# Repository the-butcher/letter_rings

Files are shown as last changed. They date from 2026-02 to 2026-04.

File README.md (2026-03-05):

# letter-rings

This is a fun project primarily for learning things. Following a specific theme for a partyI had been invited to an image of letters on each finger came to my mind, think of "LOVE" across the fingers of one hand and "HATE" on the other to have you own picture.

Since - for reasons - I did not want this as a permanent solution, something else had to be found.

I came across [8x8 LED Matrix elements](https://www.adafruit.com/product/870), small enough to be fitted to single fingers and added 3D printed rings. Cables would lead from the LED Matrix elements to a hidden [microcontroller](https://learn.adafruit.com/esp32-s3-reverse-tft-feather/overview) on my forearms. I wanted to enable the device to interact with the music being played, so I added a [microphone](https://www.adafruit.com/product/1063) for frequency analysis as well as an [orientation sensor](https://www.adafruit.com/product/4646?srsltid=AfmBOoqnGDiWn61naHonwXmNlG8PC3zfjmaNAw2MefeWkbG_hBlhx19s) so the matrices could adapt to arm position.

To avoid cable mess I ordered a simple PCB and 3D printed more parts to keep everything together. USB cables will lead to a powerbank capable to run the entire setup for many hours.

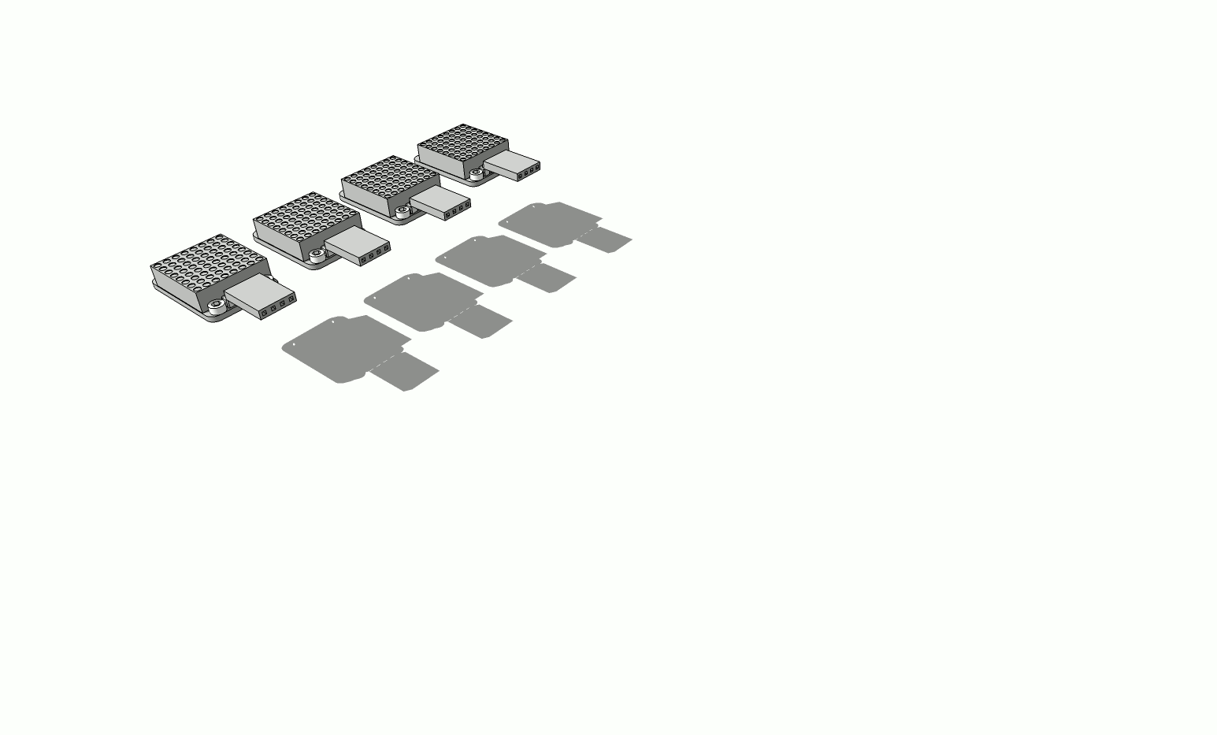
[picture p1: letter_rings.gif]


Would be nice to sync left and right? To add Bluetooth and a central device to take control I wrote an Android app, my first such app and maybe the most challenging part of this project. This app is in charge of synchronizing modes across devices.

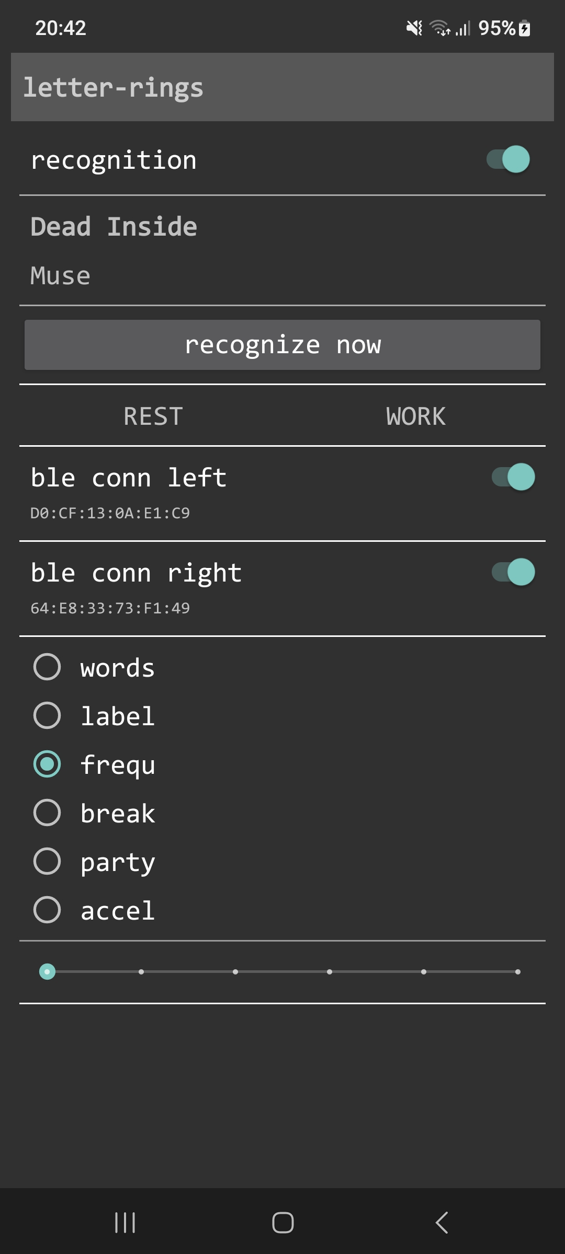
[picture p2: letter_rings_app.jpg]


There a multiple modes of operation ...

- WORDS

This mode refers to the original theme, "letters" and shows opposing pairs of words on the led matrices in radid succesion.



- LABEL

The app integrates [shazamkit](https://developer.apple.com/shazamkit/android/) for music recognition. The Android app records 10 second samples, and asks the Shazam Api for title and artist. When recognizable, tile and artist are shown as moving labels on the led matrices.

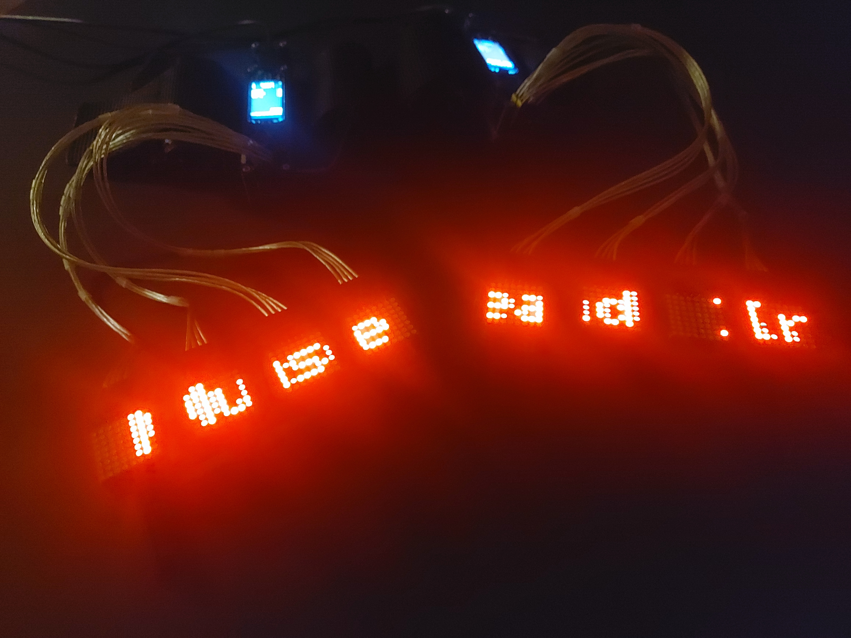
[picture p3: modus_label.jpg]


- FREQU

In this mode the devices frequency analysis is performed every 50 milliseconds (20 times per second), and the frequencies are displayed in disco style bars.

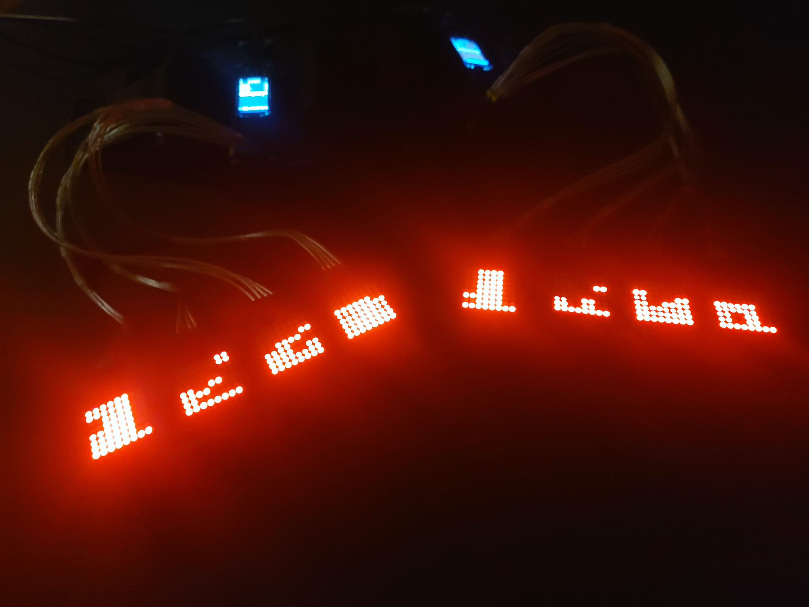
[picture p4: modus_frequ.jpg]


- BREAK

This is a "silent" mode, i.e. for when a conversation happens. A single dot travels through the led matrices.

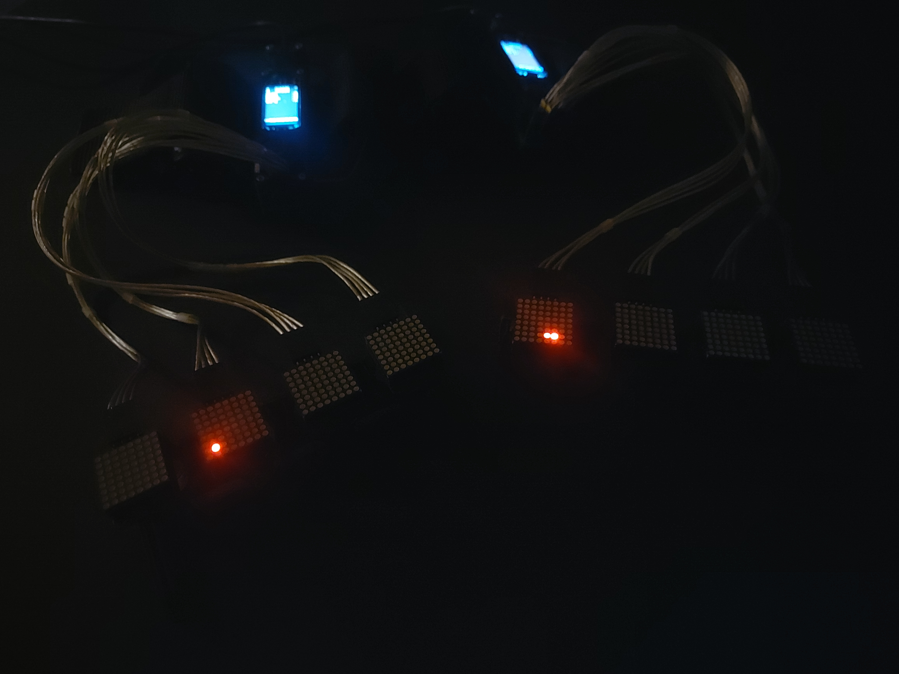
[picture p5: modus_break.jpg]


- ACCEL

Unfortunately no picture ... the orientation sensor records movements and upon detection of comment movement, i.e. both hands are held together, a PACMAN animation will run, consuming anything previously drawn on the matrices ;)

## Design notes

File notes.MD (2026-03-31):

✔️ reply to host

- android app
  ~~ try to identify code that can fail and handle errors accordingly, read more BLE tutorials
  ~~ possible/important to regularly check for BLE device having become available?
  ✔ lockability in app to prevent accidental touch events
  ✔ editability for labels in app 
  ❌ when the device disconnects before the gatt-services are in place there is no event or other notification
  ❌ attempting to connect from this state returns the app to a stable state (gatt connect fails and the UI shows the button again after that)
  ✔ integrate ChatGPT word list
  ✔ adapt the app so changes apply to all connected devices, this will simplify the UI and reduce room for error
  ✔ address does not hide when connection is lost
  ✔ generally no further bluetooth scans are done once a device connection is lost
  ✔ brightness slider
  ✔ have the catalog in a central place and reuse
  ✔️ learn how to parse the matchResult, including no-match cases
  ✔️ have continous parsing at specific intervals (i.e. 1 minute)
  ✔️ gatt connection to 2(!) devices, if that does not work maybe one device being server, one being client could be an alternative
  ✔️ find out about message size and how to split texts if needed
  ✔ handle GATT disconnect (update UI), roughly in place, but needs revisit,
  ✔ a switch disconnect in the app does not disconnect the device!

- esp
  ✔ trigger for kitt animation
  ✔ device does not return from PRI to Any :: did switch to WORDS due to false positive W pattern recognition
  ✔ actually render kitt animation depending on DTERM setting
  ✔ return all matrices to their original brightness when done with drawing the kitt animation
     -- does not work when switching modus while still in GAMKN animation, but can be recovered by manually setting brightness
  ~~ test with full setup, on arms and powerbank, wear for a while to discover problems, uncomfortable spots, short cables, ...
  ~~ check any thinkable maximum in terms of device orientation and be sure there is no problem throughout orientations
  ~~ test with high volume and noise as good as possible, experiment with gain settings on the microphone
     - https://leobot.net/tutorial/1067?srsltid=AfmBOopGwK3bNLB8GH9lWKwbYeUN1UAsiPBQsh7GJRLy7i_L0Uc4ghWd
  ✔ when entering words mode through gesture it can take a few seconds for the first words to appear
     -- also when changing UP/DOWN orientation it may take a bit
  ❌ maybe better display in accel mode, where the coefficient draws a bar with a threshold marker rather than just a number
  ✔ belts are a bit short when leading over the batteries :: TODO :: good enough?
  ✔ maybe it would work to record some accel patterns (i.e. bumping hands n-times, circling a hand), then calculating coefficients like in accel mode against those pattersn.
    ✔ determine duration a coefficient calculation consumes to get a feeling how often this can be done within loop limits
	✔ what would happen in case this works? - mode switch, "recognize now", ...
	✔ how would recording patterns work?
	✔ would recorded patterns have to be longer than the currently used accel pattern for pairing?
  ✔ condition when in accel mode where device becomes sluggish :: was due to extraDelay having large values after mode change
  ✔ introduce extra-delay
  ❌ introduce mutex around accelB (?) :: maybe not needed the way it is implemented, copying values into accelB
  ✔ do regression testing for all modes, especially acceleration related
  ✔ dont write to display after a certain time (1 minute, 5 mintues, ...) in an attempt to reduce noise and to save resources overall
    ✔ backlight could be off/low (even though the constant current likely does not introduce too much signal noise)
    ✔ wake the display upon config change through BLE
	✔ wake the display upon any button press
  ✔ reprint the pla_top part with a better mic hole center
    ✔ could also have cable fixture all around the dupont plugs
  ✔ reprint the usb cable fixture a tad higher and an opening that allows the cable diameter to be inserted, but not the larger diameter between plug and cable
  ✔ should brightness be adjustable beyond 5 :: 10 maybe?
  ✔ not sure if cubic curve still displays :: TODO :: check
  ❌ first call to party mode does not put the device into initial label mode, later calls work as expected
  ✔ make correlation threshold (0.80 currently) configurable to prevent weird behaviour when actually at the party and try to find possible default configuration
    ✔ new characteristic (like light)
	✔ slider in app
	✔ config in device
  ✔ test and measure the usb-c cables
    ✔ draw sensor protection and cable hold
    ✔ print and mount
  ✔ documentation
    ✔ github readme
    ✔ pictures, video for github and twitter
  ✔ print new ring holders
    ✔ ring holders could be more modular
    ✔ a single ring holder may offer better hold and protection for a single ring
      ✔ right hand is 23-24-23-20
      ✔ left hand is 24-24-22-20
  ✔ map raw bands to screen/matrix space
  ✔ build some sort of average from the most recent band values
  ✔ display delta from current measurement to average (aka less or more volume than previously)
  ❌ darken the green orientation sensor led with black edding
  ✔ modus accel is considerably slower when actually paired :: maybe the sens increase to 250ms :: solved with splitting the secondary tasks
  ✔ check how long a display write would normally consume, then maybe implement redraw regions to save some of that time
    ✔ was 14ms, now down to 5ms
  ✔ there should to be a "conversation" modus, where the leds are off or only a "standby" led is on
    ❌ any gesture to enable/disable this mode?
  ❌ sending or receiving through esp-now appears to disturb frequencies, try to move send calls to primary loop, receive would be more difficult :: does not work
  ❌ there is occasional lag when drawing matrices, where it seems the bitmap pos has proceeded multiple steps (~3) before an actual redraw
  ✔ mabe use the free 23mm for the right ring-finer (22 is a bit tight there)
  ✔ need another 24mm ring for left index finger (23 wont fit)
  ✔ it seems like high frequencies are over-represented in the spectrum
  ✔ check if order 3 regression on frequencies is OK :: seems to work better than order 2
  ✔ separate word sets for left and right
  ✔ have a mode (name?) where after a new label and some timeout it goes back to frequ
    ❌ could be standard, labels do not make much sense without recognition, therefore a new label could just put the decive in temp label mode
  ❌ any mode where altering brightness would add value?
  ✔ have proper matrix UP/DOWN flip in all modes
  ✔ unify method names Matrices vs. Matrix
  ✔ clearXXX function, execute properly after modus switch
  ✔ dim TFT a while after the last button press https://forums.adafruit.com/viewtopic.php?t=174096
  ✔ be able to switch modes
    ✔ through display
    ❌ through gesture (?)
    ✔ through bluetooth / mobile
  ❌ any other attractive modes?
    ❌ a mode "shaking" random chars by acceleration / position
    ❌ a mode that would write the word "beer" when lifting a bottle, would have to be a specific orientation change in a specific amount of time
    ❌ "collab" mode where people can "inject" labels
      ❌ would there be a non-backend solution?
      ❌ enter labels on a public website
      ❌ app fetches label and
      ❌ could this be a simple php solution working with a text or json file for storage?
    ❌ "kitt mode"
    ❌ a single dot travelling left to right and back
  ✔ any way to determine when left and right are held in alignment?
  ✔ setup task to read orientation in short intervals and keep track of the last n (some power of 2, maybe 32) acceleration vectors
  ✔ create esp-now connection between left and right
  ✔ send acceleration vectors to other device in regular intervals
  ✔ align vectors time-wise (how?)
  ✔ calculate pearson correlation coefficient between incoming acceleration data and own acceleration data
  ✔ see if this produces usable similarity results
  ✔ if both devices agree to have similar acceleration values unlock some (yet to be defines) two device mode
  ✔ should both devices always have the same mode?
  ✔ first device detecting similarity takes the lead
  ✔ other device will not need to check for similarity while paired
  ✔ leading device sends drawing codes, ie. kitt bar signal
  ✔ non-leading device needs to know when similarity was lost
  ❌ could be a kitt style animation (which device will be in charge of position?)
  ✔ could be a pacman style animation (which device will be in charge of position?)
  ✔ full width of matrices needs to be accounted for when paired :: with proper rotation
  ✔ the PRI device will also have to be in charge of maintaining a unique up/down orientation
  ❌ voice recognition for 4 letter words ;)
  ✔ ignore invalid titles for the runLabel
  ✔ maybe have a "song" mode that will show artist and title for a given time, then go back to frequencies
  ✔ any way to synchronize left and right in word mode?
  ✔ let the android app have the central role in words mode (only if connected)
  ✔ let the android app send pairs of words in regular intervals
  ✔ change words mode so that there always is a target word in words mode and a prepicked set of transition words
  ✔ when not connnected the devices can pick target words themselves, when connected the devices will wait for target words coming in over bluetooth
  ✔ define pairs of opposing words
  ✔ initial values of radio buttons after connect
  ✔ create a left UI version (?)
  ✔ screen could be oriented "upwards" to have an orientation common to left and right
  ✔ take care of readability (no font size = 1)
  ✔ byte to string parsing in the ESP32
  ✔️ microphone POC in the ESP32, preferrably amplifier style, but could also be led matrix brightness
  ✔ validate possibility of multiple led matrices on one i2c line
  ❌ could there be a generic blend function for labels?
  ❌ how would different lengths of labels be handled?
  ❌ original label longer than new label
  ❌ example:
  ❌ this is a very very very long label
  ❌ short label
  ❌ original label shorter than new label
  ✔ create some blend magic from one character to another
  ✔ could maybe work with offscreen canvas
  ✔ look at canvas.getBuffer()
  ✔ maybe a few random sequences including the number 0-63 and gradually changing from src to target values would do the trick
  ✔ check if there is a shuffle method for arrays in arduino
  ❌ rotate display upon hand position using blend effect
  ❌ current buffers of A and D (and B and C) would have to be swapped and rotated
  ✔ Lackstift gelb für Kabelmarkierungen @ müller
  ✔ punkt bei SCL auf der LED Matrix
  ❌ kurzes stück gelber schraumpfschlauch am SCL kabel, beidseitig
  ✔ und / oder dupont stecker auf der SCL seite gelb markiert  

✔ pcb
✔ order pcb after multi-matrix i2c validation

LOVE ICON GAIN HYPE UNDO COOL HOPE KISS MOON FEEL HELP DEAL FACT GAME KIND MIND DARE EARN WELL GROW JUMP KEEP BOLD CALM DEEP EASY GOOD FULL GLAD HIGH NEAR PULL PLUS SAVE FAST LIKE FREE
HERO BEST BODY DEAR FACE FLOW LEAD USER YEAH PEAK FUND LIST NEWS PAIR LIST NOTE SELF BASS FINE BLUE HALF LIVE LONG HOUR LOOK MARK MOVE LIFT GOAL BAND SOFT CARE PURE FUND STAY MORE WARM
LAMB TEAM VIEW REAL HAVE LINK RISE RELY WISH WAIT TALK REST MANY RICH KNOW JOIN RIDE TIDY HUGE HEAL NICE OKAY FAIR NEAT TRUE LIFE

HATE FAIL GANG JUNK FAKE BAIT CAGE SCAR SLOW WOLF PAIN TINY LUSH FIRE FUCK LESS LOSS BURN DENY FALL FEAR HURT KILL NONE EVIL DULL FOUL GRIM DAMN GORE GOSH HELL LATE DUST DARK DUTY RISK
WARN SLIP UGLY WILD VAIN POOR MEAN RUDE SORE VOID ANTI DIRE COPE COST PUSH MYTH URGE RAIN REDO NEED SEEM LONE VAST PALE SICK RARE BEEF FOOL DEAF DRUG ITCH PITY LACK WANT SEEK TRIP DOWN
GREY RULE WORK TASK STOP LOUD MUST GIVE LOSE TORN ONLY SOLO TRAP FLOP QUIT SUNK HOWL ENVY CYST COLD DROP BASE FLEE OVER HARD PASS

https://www.powerthesaurus.org/huge/antonyms

STEW SOUP
LOVE HATE
REAL FAKE
WARM COLD
MANY NONE
FAST SLOW
KIND GRIM
GOOD EVIL
TAKE GIVE
WELL SICK
HOPE FEAR
FACT MYTH
RISE FALL
MORE LESS
MOVE STOP
REST WORK
HEAL HURT
LIFT DROP
SOFT HARD
CALM LOUD
RICH POOR
PURE FOUL
NICE MEAN
PEAK BASE
PULL PUSH
LAMB WOLF
TALL TINY
FULL HALF
STAY FLEE
UNDO REDO
LIVE PASS
FIND LOSE
GAIN LOSS
OPEN SHUT
EAST WEST
HIGH DEEP
DAWN DUSK
ROCK ROLL
GOLD IRON
SAFE RISK
GROW FADE
CODE DATA
ROPE KNOT
BEER WINE
SKIN BONE
FACE MASK
MIND BODY
HIDE SEEK
LUCK FATE
WEAK FIRM

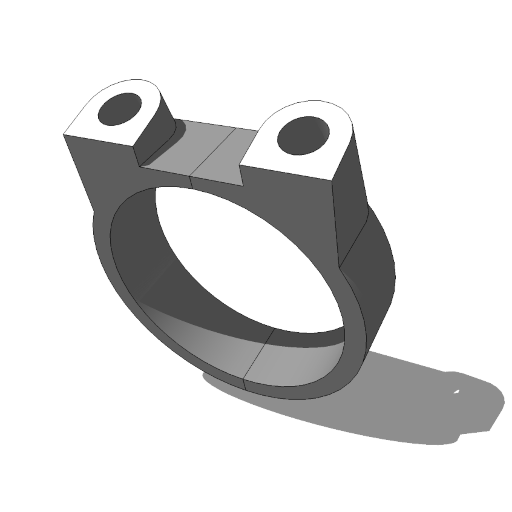
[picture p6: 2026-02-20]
letter_rings.png

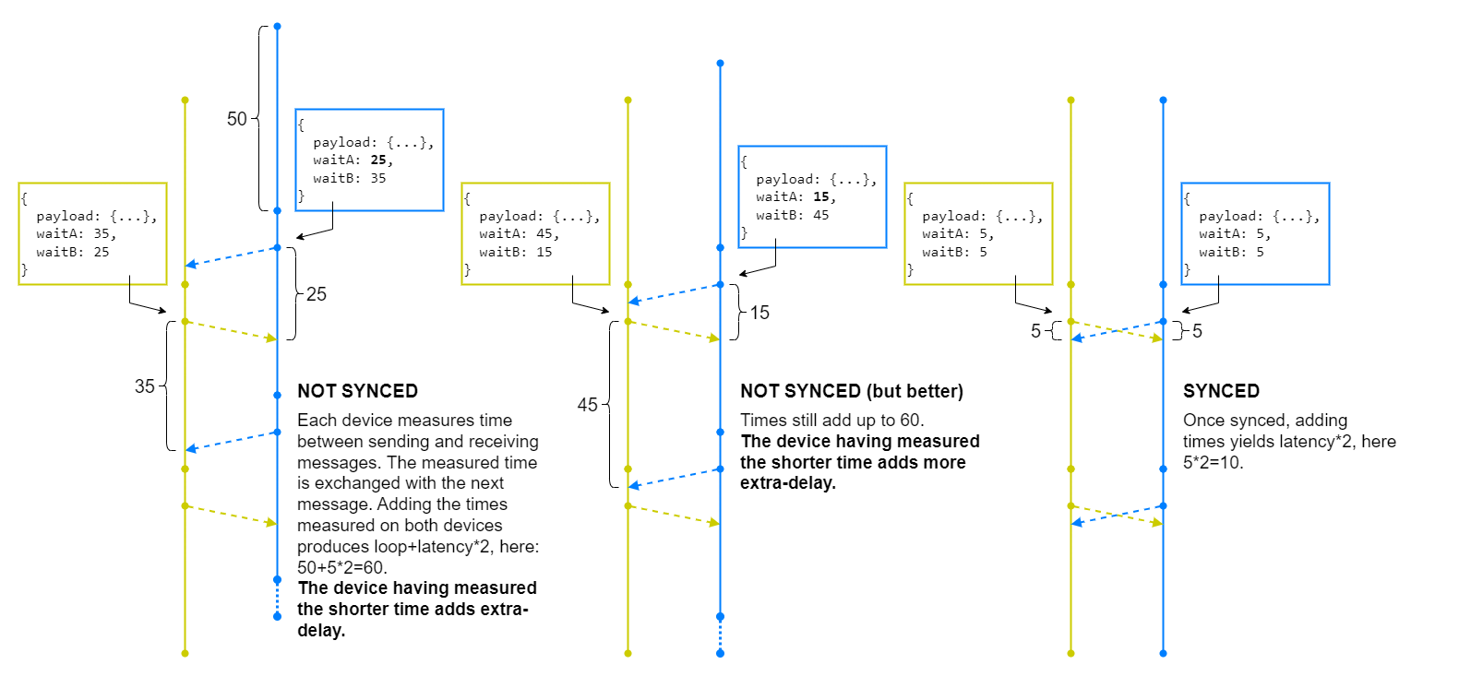
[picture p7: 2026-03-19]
espnow_sync.drawio.png

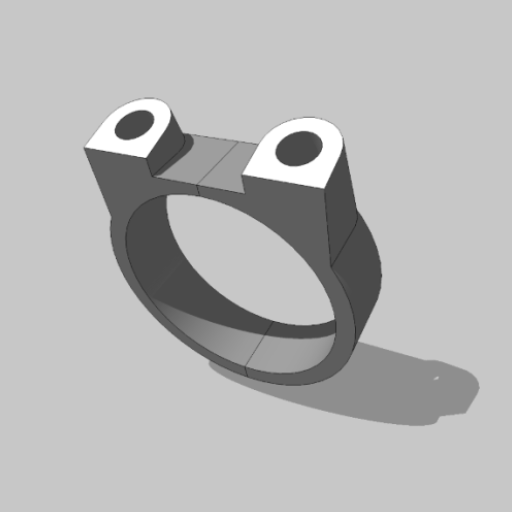
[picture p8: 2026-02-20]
letter_rings_android/letter_rings/src/main/ic_launcher-playstore.png

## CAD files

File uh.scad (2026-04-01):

$fn=30;

// https://www.desmos.com/calculator/ihjmltaprq?lang=de

/*
radiusB = 15; // base radius
incremH = 1;
incremA = 10;
incremL = 6.5; 
heightH = 150;
heightM = heightH - incremH;
powerP = 0.55; // larger = pointier
*/

/*
radiusB = 13; // base radius
incremH = 1;
incremA = 10;
incremL = 6.5; 
heightH = 145;
heightM = heightH - incremH;
powerP = 0.55; // larger = pointier
*/

/*
radiusB = 12.8; // base radius
incremH = 1;
incremA = 10;
incremL = 6.5; 
heightH = 145;
heightM = 15;
powerP = 0.55; // larger = pointier
*/

radiusB = 10.8; // base radius
incremH = 1;
incremA = 10;
incremL = 6.5; 
heightH = 145;
heightM = 15;
powerP = 0.55; // larger = pointier


minAngle0 = -105;
maxAngle0 = 105 - incremA;

function handleHeightA(
    h0,
    h1,
    radiusC0,
    radiusC1,
    centerO0,
    centerO1,
    angleCC0,
    angleCC1,
    centerAX0,
    centerAY0,
    centerAX1,
    centerAY1, 
    centerBX0,
    centerBY0,
    centerBX1,
    centerBY1
) = 
    [
        for ( angleA0 = [minAngle0 : incremA : maxAngle0] )
            
            let (vertexAX00 = centerAX0 + cos(angleCC0 + angleA0) * radiusC0)
            let (vertexAY00 = centerAY0 + sin(angleCC0 + angleA0) * radiusC0)
            let (vertexAX01 = centerAX0 + cos(angleCC0 + angleA0 + incremA) * radiusC0)
            let (vertexAY01 = centerAY0 + sin(angleCC0 + angleA0 + incremA) * radiusC0)
            
            let (vertexAX10 = centerAX1 + cos(angleCC1 + angleA0) * radiusC1)
            let (vertexAY10 = centerAY1 + sin(angleCC1 + angleA0) * radiusC1)
            let (vertexAX11 = centerAX1 + cos(angleCC1 + angleA0 + incremA) * radiusC1)
            let (vertexAY11 = centerAY1 + sin(angleCC1 + angleA0 + incremA) * radiusC1)
            
            [
                [vertexAX00,vertexAY00,h0],[vertexAX10,vertexAY10,h1],[vertexAX01,vertexAY01,h0],
                [vertexAX01,vertexAY01,h0],[vertexAX10,vertexAY10,h1],[vertexAX11,vertexAY11,h1]
            ]
 
    ];
        
function handleHeightB(
    h0,
    h1,
    radiusC0,
    radiusC1,
    centerO0,
    centerO1,
    angleCC0,
    angleCC1,
    centerAX0,
    centerAY0,
    centerAX1,
    centerAY1, 
    centerBX0,
    centerBY0,
    centerBX1,
    centerBY1
) = 
    [
        for ( angleB0 = [minAngle0 : incremA : (105 - incremA)] )
            
                let (vertexBX00 = centerBX0 + cos(angleCC0 + angleB0 + 180) * radiusC0)
                let (vertexBY00 = centerBY0 + sin(angleCC0 + angleB0 + 180) * radiusC0)
                let (vertexBX01 = centerBX0 + cos(angleCC0 + angleB0 + 180 + incremA) * radiusC0)
                let (vertexBY01 = centerBY0 + sin(angleCC0 + angleB0 + 180 + incremA) * radiusC0)
                
                let (vertexBX10 = centerBX1 + cos(angleCC1 + angleB0 + 180) * radiusC1)
                let (vertexBY10 = centerBY1 + sin(angleCC1 + angleB0 + 180) * radiusC1)
                let (vertexBX11 = centerBX1 + cos(angleCC1 + angleB0 + 180 + incremA) * radiusC1)
                let (vertexBY11 = centerBY1 + sin(angleCC1 + angleB0 + 180 + incremA) * radiusC1)
            
            [
                [vertexBX00,vertexBY00,h0],[vertexBX10,vertexBY10,h1],[vertexBX01,vertexBY01,h0],
                [vertexBX01,vertexBY01,h0],[vertexBX10,vertexBY10,h1],[vertexBX11,vertexBY11,h1]
            ]
 
    ];        

function handleHeight(h0, h1) =

    let (radiusC0 = pow((heightH - h0) * pow(radiusB, 1 / powerP) / heightH, powerP))
    let (radiusC1 = pow((heightH - h1) * pow(radiusB, 1 / powerP) / heightH, powerP))

    let (centerO0 = sin(15) * radiusC0)
    let (centerO1 = sin(15) * radiusC1)

    let (angleCC0 = h0 * incremL)
    let (angleCC1 = h1 * incremL)
    // echo(h, centerO, radiusC0);

    // semiprofile A
    let (centerAX0 = cos(angleCC0) * centerO0)
    let (centerAY0 = sin(angleCC0) * centerO0)
    let (centerAX1 = cos(angleCC1) * centerO1)
    let (centerAY1 = sin(angleCC1) * centerO1) 

    // semiprofile B
    let (centerBX0 = cos(angleCC0) * -centerO0)
    let (centerBY0 = sin(angleCC0) * -centerO0)
    let (centerBX1 = cos(angleCC1) * -centerO1)
    let (centerBY1 = sin(angleCC1) * -centerO1) 
    
    [
        handleHeightA(
            h0,
            h1,
            radiusC0,
            radiusC1,
            centerO0, 
            centerO1,
            angleCC0,
            angleCC1,
            centerAX0,
            centerAY0,
            centerAX1,
            centerAY1,
            centerBX0,
            centerBY0,
            centerBX1,
            centerBY1         
        ),
        handleHeightB(
            h0,
            h1,
            radiusC0,
            radiusC1,
            centerO0, 
            centerO1,
            angleCC0,
            angleCC1,
            centerAX0,
            centerAY0,
            centerAX1,
            centerAY1,
            centerBX0,
            centerBY0,
            centerBX1,
            centerBY1         
        )        
    ];

function iterateHeights() =
    [
    for ( h0 = [0 : incremH : heightM] ) // heightM
        let (h1 = h0 + incremH)
        handleHeight(h0, h1)
    ];
    

function flatten(l) = [ for (a = l) for (b = a) b ] ;
    
function indices(coordCount) =
    [
        for ( index = [0 : 3 : coordCount - 3] )
            [index, index + 1, index + 2]
    ];

module draw_horn() {
    
    points = flatten(flatten(flatten(iterateHeights()))); 
    // echo(points);
    
    triangles = indices(len(points));
    // echo(triangles);
    
    echo(len(points));
    
    polyhedron(points=points, triangles = triangles);    
    
} 

draw_horn();

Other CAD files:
cc.skp
letter_rings_4stl.skp

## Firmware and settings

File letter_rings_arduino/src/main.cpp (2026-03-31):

#include <Arduino.h>

#include "Blesrv.h"
#include "Buttons.h"
#include "Device.h"
#include "Display.h"
#include "Matrices.h"
#include "Microphone.h"
#include "Nowsrv.h"
#include "Orientation.h"
#include "GamOL.h"
#include "Chars.h"

uint16_t pixelPos = 0;
int16_t labelPos = 33;
String mainLabel = "";
uint16_t labelWidth = 32;  // start value, will be recalculated upon first text change

String mainWord = "";
uint8_t wordProgress = 0;

uint64_t lastWordUpdateMillis = 0;
uint64_t lastLabelUpdateMillis = 0;
uint64_t lastGamOLThresholdMillis = 0;

const int16_t BITMAP_RESET_POS = -10;
int16_t bitmapPos = BITMAP_RESET_POS;

uint64_t millisAPri = 0;

#if USE_SERIAL_LOOP_OUTPUT == true
uint64_t totalLoopMillis = 0;
uint64_t totalLoopNumber = 0;
uint64_t lastLoopMillis = 0;
#endif

bool exceedsWordUpdateInterval(uint64_t currMillis) {
    return (currMillis - lastWordUpdateMillis) > WORD_UPDATE_INTERVAL_MS;
}

bool exceedsPartyLabelDuration(uint64_t currMillis) {
    return (currMillis - lastLabelUpdateMillis) > PARTY_LABEL_DURATION_MS;
}

/**
 * check if the GamOL animation has run a full cycle
 * will always return true until lastGamOLThresholdMillis has been set to a value higher than zero,
 * this is to prevent a GamOL animation from starting right after a device boot
 */
bool exceedsGamOLThresholdDuration(uint64_t currMillis) {
    if (lastGamOLThresholdMillis == 0) {
        return true;
    } else {
        return (currMillis - lastGamOLThresholdMillis) > GAMOL_______DURATION_MS;
    }

}

modus_________e determineModus() {

    uint64_t currMillis = millis();

    // label needs to be checked outside of MODUS________LABEL clause, so a correct decision can be made when in MODUS________PARTY
    if (Device::label != mainLabel) {
        labelWidth = Matrices::matrixA.getLabelWidth(Device::label);
        mainLabel = Device::label;
        lastLabelUpdateMillis = currMillis;
    }

    modus_________e modus = Device::getCurrModus();
    // if in accel mode and paired -> run pacman, fallback to previous mode if not paired
    if (modus == MODUS________ACCEL) {

        if (USE__FORCE_______GAMXX) {

            modus = MODUS____GAMKN_PRI; // temporary for initial testing

        } else if (Device::getDeviceRole() == DEVICE_ROLE_____PRI) {

            if (Device::getCurrDterm() == DTERM________GAMPM) {
                modus = MODUS____GAMPM_PRI;
            } else if (Device::getCurrDterm() == DTERM________GAMKN) {
                modus = MODUS____GAMKN_PRI;
            }

        } else if (Device::getDeviceRole() == DEVICE_ROLE_____SEC) {

            if (Device::getCurrDterm() == DTERM________GAMPM) {
                modus = MODUS____GAMPM_SEC;
            } else if (Device::getCurrDterm() == DTERM________GAMKN) {
                modus = MODUS____GAMKN_SEC;
            }

        } else {

            modus = Device::getPrevModus();

            if (Orientation::isAboveSignificantThreshold(ACCELERATION_SIG_THRES)) {
                if (exceedsGamOLThresholdDuration(currMillis)) { // init field upon first exeeding threshold
                    GamOL::readFieldState();
                }
                lastGamOLThresholdMillis = currMillis;
            }

            // keep the GamOL animation running even after a significant threshold event
            if (!exceedsGamOLThresholdDuration(currMillis)) { // Game of Life
                modus = MODUS________GAMOL;
            }

        }

    }

    // if in party mode, make a decision for either label or frequency
    if (modus == MODUS________PARTY) {
        modus = exceedsPartyLabelDuration(millis()) ? MODUS________FREQU : MODUS________LABEL;
    }

    return modus;
}

/**
 * run anything that will lead to matrix or display updates
 */
void runLoopTaskDisplay(void* pvParameters) {

    while (true) {

        uint64_t currMillis = millis();

        modus_________e determModus = determineModus();

        orientation___e matricesOrientation = Device::getOrientation();
        if (matricesOrientation == ORIENTATION______UP && Orientation::getOrientation().y > 20) {
            Device::setOrientation(ORIENTATION____DOWN);
        }
        if (matricesOrientation == ORIENTATION____DOWN && Orientation::getOrientation().y < -20) {
            Device::setOrientation(ORIENTATION______UP);
        }

        // common display redraws (have to be in this loop to keep the clip logic in a single place)
        // this will happen at varying intervals, however all of them are in the same magnitude ~100-250ms
        Display::drawConfig(); // only draws when the needsConfigRedraw is true
        Display::drawConnection(); // only draws when the connection state changed
        Display::drawDeviceRole();  // little box indicators, only drawn after a change to the role
        Display::drawOrientation(); // will only draw if orientation was properly initialized
        Display::drawSignal(); // will always draw
        Display::drawMatrixState();  // I2C init states of matrices, only draws once

        if (determModus == MODUS________CHARS) {

            Chars::step();

            Matrices::clear(CLEAR_MATRIX_CANVAS | CLEAR_MATRIX___DISP);
            for (int i = 0; i < CHARS______________NUM; i++) {
                Matrices::drawChar(Chars::chars[i]);
            }

            vTaskDelay(100);

        } else if (determModus == MODUS________WORDS) {

            if (exceedsWordUpdateInterval(currMillis)) {
                uint64_t randomWordIndex = random(0, WORD_COUNT - 1);
                Device::word = WORDS[randomWordIndex];  // will be picked up some lines down
            }

            if (Device::word != mainWord) {
                mainWord = Device::word;
                wordProgress = 0;
                lastWordUpdateMillis = currMillis;
            }

            if (wordProgress < WORD_____TRANSITION_NUM) {
                wordProgress++;
                String word = WORDS[random(0, WORD_COUNT - 1)];
                Matrices::drawWord(word);
                Display::drawText(word);
                vTaskDelay(75);
            } else {
                if (wordProgress == WORD_____TRANSITION_NUM) {
                    wordProgress++;
                    Matrices::drawWord(mainWord);
                    Display::drawText(mainWord);
                }
                vTaskDelay(100);
            }

        } else if (determModus == MODUS________LABEL) {

            Matrices::drawLabel(mainLabel, labelPos);
            Display::drawText(mainLabel);

            if (labelPos < -labelWidth) {  // all the way out to the left
                labelPos = 32;             // reset to right border
            }
            labelPos--;

            vTaskDelay(max(50.0f, 150.0f - Orientation::getOrientation().z));

        } else if (determModus == MODUS________FREQU) {  // frequency

            // Matrices are drawn in primary loop
            Display::drawFrequ();

            vTaskDelay(100);  // effectively do nothing, just wait a bit

        } else if (determModus == MODUS________BREAK) {  // frequency

            Matrices::clear(CLEAR_MATRIX_CANVAS | CLEAR_MATRIX___DISP);
            Matrices::drawPixel(pixelPos, 6, LED_ON);

            Display::drawText("");

            if (pixelPos > 31) {  // all the way out to the left
                pixelPos = 0;     // reset to right border
            }
            pixelPos++;

            vTaskDelay(250);

        } else if (determModus == MODUS____GAMPM_PRI || determModus == MODUS____GAMPM_SEC) {

            bitmaps_______t bitmaps = Device::getCurrBitmaps();

            Matrices::clear(CLEAR_MATRIX_CANVAS);
            // first two calls clear the bitmap ahead and behind
            Matrices::drawBitmapWithOrientation(BITMAP_STORE[bitmaps.bitmapA.bitmap], bitmaps.bitmapB.offset + 2, LED_OFF, bitmaps.orientation);
            Matrices::drawBitmapWithOrientation(BITMAP_STORE[bitmaps.bitmapA.bitmap], bitmaps.bitmapB.offset - 2, LED_OFF, bitmaps.orientation);
            // third call draws into the space cleared by the previous calls
            Matrices::drawBitmapWithOrientation(BITMAP_STORE[bitmaps.bitmapB.bitmap], bitmaps.bitmapB.offset, LED_ON, bitmaps.orientation);

            Display::drawAcceleration();

            vTaskDelay(100);

        } else if (determModus == MODUS____GAMKN_PRI || determModus == MODUS____GAMKN_SEC) {

            ledbar________t ledbar = Device::getCurrLedbar();

            Matrices::drawLedbar();

            Display::drawAcceleration();

            vTaskDelay(50);

        } else if (determModus == MODUS________GAMOL) {

            GamOL::drawFieldState();
            GamOL::stepFieldState();

            Display::drawAcceleration();

            vTaskDelay(75);

        } else {

            // ACCEL = 6
            Serial.print("unknown determModus: ");
            Serial.println(String(determModus));
            vTaskDelay(100);

        }

        // prepare the clip-buffer that will actually be drawn to the display
        Display::writeClip();

    }

}

void runLoopTaskGeneral(void* pvParameters) {

    uint64_t counterGeneral = 0;
    while (true) {

#if USE_SERIAL_LOOP_OUTPUT == true
        Serial.print("loopMillis (avg): ");
        Serial.print(String(totalLoopMillis * 1.0 / totalLoopNumber, 2));
        Serial.print(", totalLoopNumber: ");
        Serial.print(String(totalLoopNumber));
        Serial.print(", lastMillis: ");
        Serial.println(String(lastLoopMillis));
#endif

        if (Device::getCurrModus() == MODUS________ACCEL) {  // must refer to actual curr device modus or it will not happen due to prevMode

            modus_________e determModus = determineModus(); // see what central logic tells about modus
            if (determModus == MODUS____GAMPM_PRI) { // move bitmaps forward when in GAMPM_PRI

                if (counterGeneral % 2 == 0) { // every second iteration of this loop => every 100ms

                    if (bitmapPos > 64) {
                        bitmapPos = BITMAP_RESET_POS;
                    }
                    bitmapPos++;

                    // get and alter bitmaps
                    bitmaps_______t bitmaps = Device::getCurrBitmaps();
                    bitmaps.bitmapB.offset = bitmapPos;
                    bitmaps.bitmapB.bitmap = (bitmap________e)((bitmapPos + 64) % 2);  // open and close mouth, keep the number going into modulo in positive range
                    bitmaps.orientation = Device::getOrientation();
                    Device::setCurrBitmaps(bitmaps);

                }

            } else if (determModus == MODUS____GAMKN_PRI) { // move values forward when in MODUS____GAMKN_PRI

                ledbar________t ledbar = Device::getCurrLedbar();
                ledbar.offset = ledbar.offset + 1;
                Device::setCurrLedbar(ledbar);

            }

        } else {
            bitmapPos = BITMAP_RESET_POS;
        }

        counterGeneral++;
        vTaskDelay(50);

    }

}

/**
 * primary loop running on core-1
 * attempts have been made that everything disturbing the microphone in terms of unwanted frequencies is happening here
 * however, ESP-NOW and Bluetooth still consume energy and produce unwanted signal since the callback functions run async from this loop
 */
void runLoopTaskPrimary(void* pvParameters) {

    while (true) {

        millisAPri = millis();

        modus_________e determModus = determineModus();
        if (determModus == MODUS________FREQU) {
            Microphone::read();
            Matrices::drawBars();  // 7ms
        }

        // ~29ms here when in frequency mode

        while ((millis() - millisAPri) < 30) {
            vTaskDelay(1);
            yield();
        }

        modus_________e deviceModus = Device::getCurrModus();
        if (deviceModus == MODUS________ACCEL) { // must refer to actual curr device modus or it will not happen due to prevMode
            Nowsrv::sendDeviceData(determModus);
        }

        Matrices::write();  // only writes if required

        // only writes if required
        // with clipBuffer a single write consumes ~5ms
        Display::writeCopy();

        // ~42ms here when in frequ/accel mode

        while ((millis() - millisAPri) < 43) {
            vTaskDelay(1);
            yield();
        }

        Orientation::read();

#if USE_SERIAL_LOOP_OUTPUT == true
        lastLoopMillis = (millis() - millisAPri);
        totalLoopMillis += lastLoopMillis;
        totalLoopNumber++;
#endif

        // ~49ms here when in frequ/accel mode

        while ((millis() - millisAPri) < MAIN_LOOP_______DEST_MS) { // wait until 200 millis have passed since millisA
            yield();
        }

        if (deviceModus == MODUS________ACCEL) { // must refer to actual curr device modus or it will not happen due to prevMode
            uint64_t millisWaitB = Orientation::getMagnitudesB().millisWait;
            uint64_t millisWaitA = Orientation::getMagnitudesA().millisWait;
            // some extra delay to sync devices, once synced this would be in the one-digit millisecond range
            // some safety added to not get caught with long delays in edge cases
            if (millisWaitA < millisWaitB && millisWaitA >= 4 && millisWaitA < (MAIN_LOOP_______DEST_MS * 2)) {
                uint64_t extraDelay = millisWaitA / 4L;
#if USE_SERIAL_SYNC_OUTPUT == true
                Serial.print(DEVICE____________SIDE);
                Serial.print(", ms: ");
                Serial.print(String(millis()));
                Serial.print(", extraDelay: ");
                Serial.println(String(extraDelay));
#endif
                vTaskDelay(extraDelay);
            }

        }

    }

}

#if USE_SERIAL__MIC_OUTPUT == true
void runLoopTaskMicVals(void* pvParameters) {

    while (true) {

        Serial.print("basis: ");
        Serial.println(String(Microphone::basis, 2));
        Serial.print("scale: ");
        Serial.println(String(Microphone::scale, 5));

        vTaskDelay(2000);
    }

}
#endif

void setup(void) {

    Serial.begin(9600);
    delay(2000);

    // https// forum.arduino.cc/t/shuffle-an-array-of-ints/333494/6
    // use a different seed value so that we don't get same result each time we run this program
    // this is an attempt to have different random word orders across device starts and therefore different word orders
    randomSeed(analogRead(A0));

    String separator = "----------------------";
    Serial.println(separator);
    Serial.println(DEVICE____________NAME);
    Serial.println(separator);

    Device::powerup();
    delay(100);

    Serial.println(separator);

    Display::powerup();
    delay(100);

    Matrices::powerup();
    delay(100);

    Microphone::powerup();
    delay(100);

    Buttons::powerup();
    delay(100);

    Chars::powerup();
    delay(100);

    Orientation::powerup();
    delay(100);

    Serial.println(separator);

    Nowsrv::powerup();
    delay(100);

    Blesrv::powerup();
    delay(100);

    xTaskCreatePinnedToCore(runLoopTaskGeneral, "run-loop-general", 10000, NULL, 2, NULL, 0);
    xTaskCreatePinnedToCore(runLoopTaskDisplay, "run-loop-display", 10000, NULL, 2, NULL, 0);
    xTaskCreatePinnedToCore(runLoopTaskPrimary, "run-loop-primary", 10000, NULL, 2, NULL, 1); // run on primary core
#if USE_SERIAL__MIC_OUTPUT == true
    xTaskCreatePinnedToCore(runLoopTaskMicVals, "run-loop-micvals", 10000, NULL, 2, NULL, 0);
#endif

    Serial.println(separator);
}


void loop() {

    delay(1000);

}

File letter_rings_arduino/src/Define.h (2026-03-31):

#define DEVICE____________LEFT false

#if DEVICE____________LEFT == true
#define COMMAND_SERVICE___UUID "791320d5-7f0a-4b58-89f6-cc2031479da5"
#define DEVICE____________SIDE "L"
#define DEVICE____________NAME "LETTER_RINGS_L"
#define ACCEPT__ROLE_DOWNGRADE false
#else
#define COMMAND_SERVICE___UUID "d0e5a78d-614b-4f8c-86cd-e782d832228f"
#define DEVICE____________SIDE "R"
#define DEVICE____________NAME "LETTER_RINGS_R"
#define ACCEPT__ROLE_DOWNGRADE true
#endif

#define USE__FORCE_______GAMXX false // when true (and mode ACCEL) mode GAMPM will be active, regardless of device pairing
#define USE__________CLIP_DRAW false // draw red clip areas on display
#define USE__FORCE_BACKLITE_ON false // when true, the display backlite will never turn off, even when the display is inactive
#define USE_SERIAL_LOOP_OUTPUT false // measure loop duration and write to console
#define USE_SERIAL__MIC_OUTPUT false // write microphone related messages (basis, scale) to the console
#define USE_SERIAL_SYNC_OUTPUT false // write sync related messages (send, revc, millis) to the console

#define COMMAND_LABEL_____UUID "067c3c93-eb63-4905-b292-478642f8ae99"  // for remote writing a label (moving over multiple matrices)
#define COMMAND_WORD______UUID "3dfde050-8432-4f2f-9366-de27c430c05c"  // for remote writing a word (static 4-letter word)
#define COMMAND_MODUS_____UUID "a8792ef9-c01c-47ee-a063-f8712bf8dd67"  // for remote reading/writing the modus
#define COMMAND_LIGHT_____UUID "28c64d42-4958-43f0-8845-5a106498bf1d"  // for remote reading/writing the light
#define COMMAND_COEFP_____UUID "cfb68865-9243-4646-af27-750d02d44a3a"  // for remote reading/writing the coefP (pairing coefficient)

#define AUDIO__________SAMPLES 512    // Must be a power of 2
#define AUDIO____SAMPLING_FREQ 40000  // Hz, must be 40000 or less due to ADC conversion time. Determines maximum frequency that can be analysed by the FFT Fmax=sampleF/2.
#define AUDIO________NUM_BANDS 16
#define AUDIO________NUM_ORDER 3
#define AUDIO________MAX_SCALE 0.0015 // a bit louder than silence (PC fan and else) which yields 0.002
#define AUDIO_BASE_SCALE_DECAY 0.9999
#define AUDIO_PEAK_______DECAY 0.96
#define AUDIO_FIT________DECAY 0.001

#define BUTTON_DEBOUNCE_MILLIS 100

#define ACCELERATION___SAMPLES 32  // ~ 1.5 seconds at a sample rate of 50ms, maybe half of that would do as well
#define COEFF________THRES_MIN 0.6
#define COEFF________THRES_MAX 0.9
#define ACCELERATION_SIG_THRES 7.0
#define ACCELERATION_TAP_THRES 5.0

#define CHARS______________NUM 6
#define CHARS______FIELD_DIM_X 40
#define CHARS______FIELD_DIM_Y 10

#ifndef Define_h
#define Define_h

#include <Arduino.h>

static const uint16_t DISPLAY__WIDTH = 135;
static const uint16_t DISPLAY_HEIGHT = 240;

// left
// bleAddress: D0:CF:13:0A:E1:C9
// staAddress: D0:CF:13:0A:E1:C8

// right
// bleAddress: 64:E8:33:73:F1:49
// staAddress: 64:E8:33:73:F1:48
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

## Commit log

2026-02-20 add word capability
    [buckle_40.skp, buckle_40.stl]
2026-02-20 add word pairs
    [buckle_40.stl]
2026-02-21 remove skb files
    [buckle_40.skp]
2026-02-22 fix issue with prevMode
    [Define.h, main.cpp]
2026-02-26 cleanup, documentation
    [letter_rings_4stl.skp]
2026-03-07 configurable coefficient
    [cc.skp]
2026-03-08 clean up kotlin code, redraw some 3D printed parts
2026-03-10 display inactive after time threshold
    [cc.skp]
2026-03-12 prepare for GAMOL
    [cc.skp]
2026-03-22 add basic pattern recognition
    [letter_rings_4stl.skp]
2026-04-01 uh for e
    [uh.scad]
